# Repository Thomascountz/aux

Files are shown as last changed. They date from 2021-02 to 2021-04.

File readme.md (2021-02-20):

# Aux countz research logo

Aux (short for auxiliary) is an internet-connected consumer electronic device that collects and displays locally captured and internet queried data.

## This Repository
This repository houses [research](research/), firmware, and hardware designs for Aux.

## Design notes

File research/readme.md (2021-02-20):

# Research
Aux requires and immense amount of research and prototyping. Each component/feature is independently documented and later integrated into final designs. Categorizing/archiving this research also allows for the output of documentation and reference material to aid to future designs.

## [Beep](beep/)
Beep contains the research and prototyping for adding audio feedback to Aux.

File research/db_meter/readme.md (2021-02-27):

# Decibel Meter

## References 
- https://blog.yavilevich.com/2016/08/arduino-sound-level-meter-and-spectrum-analyzer/

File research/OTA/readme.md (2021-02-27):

# Over-the-air Updates

## References
- https://tttapa.github.io/ESP8266/Chap13%20-%20OTA.html
- https://github.com/espressif/arduino-esp32/blob/master/libraries/ArduinoOTA/examples/BasicOTA/BasicOTA.ino
- https://docs.platformio.org/en/latest/platforms/espressif32.html#using-built-in-local-solution

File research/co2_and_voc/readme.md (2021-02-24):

# CO2 & VOC
Aux can sense eCO2 (equivalent carbon dioxide) concentrations and TVOC (total volatile organic compound) levels. Together with [temp_and_humidity](research/temp_and_humidity/), this makes up Aux's sense of indoor environment quality.

## [Firmware](/research/co2_and_vcc/firmware/)
This beep prototype is written in Arduino-compatible C++ using the [PlatformIO IDE](https://platformio.org/). Readings are read out through the serial port.

## [Hardware](/research/co2_and_vcc/hardware/)
The circuit is designed with [KiCAD](https://kicad.org/) and consists the ESP32 dev board and a S17021 (a.k.a. SHT71, HTU21, or GY21) sensor module.

## Resources
- https://learn.adafruit.com/adafruit-ccs811-air-quality-sensor/overview

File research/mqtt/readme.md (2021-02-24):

# MQTT
Aux communicates via MQTT (Message Queuing Telemetry Transport) over WIFI. 

## [Firmware](/research/temp_and_humidity/firmware/)
This MQTT prototype is written in Arduino-compatible C++ using the [PlatformIO IDE](https://platformio.org/). The MQTT client is built using the [knolleary/pubsubclient](https://github.com/knolleary/pubsubclient/tree/master/examples) library. The broker is built using the cloud-based managed tool [MyQttHub](https://myqtthub.com/).

## Hardware
This prototype doesn't require a schematic. The onboard `BUILTIN_LED` is toggled via an MQTT topic.

## Resources
- https://support.asplhosting.com/t/connecting-with-pubsubclient-with-myqtthub-arduino-client-for-mqtt/278
- https://learn.sparkfun.com/tutorials/introduction-to-mqtt/all

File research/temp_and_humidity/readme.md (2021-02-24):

# Temp and Humidity
Aux sense local temperature and humidity (via a temperature & humidity sensor) as well as query for outdoor conditions via WIFI.

## [Firmware](/research/temp_and_humidity/firmware/)
This temperature and humidity prototype is written in Arduino-compatible C++ using the [PlatformIO IDE](https://platformio.org/). Readings are read out through the serial port.

## [Hardware](/research/temp_and_humidity/hardware/)
The circuit is designed with [KiCAD](https://kicad.org/) and consists the ESP32 dev board and a S17021 (a.k.a. SHT71, HTU21, or GY21) sensor module.

## Resources
- https://github.com/adafruit/Adafruit_Si7021
- https://learn.adafruit.com/adafruit-si7021-temperature-plus-humidity-sensor
- https://learn.sparkfun.com/tutorials/si7021-humidity-and-temperature-sensor-hookup-guide
- https://revspace.nl/CJMCU-810
- https://learn.sparkfun.com/tutorials/ccs811-air-quality-breakout-hookup-guide

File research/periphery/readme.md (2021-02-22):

# Periphery

Periphery is all of the research that sits adjacent to the project, rather than specifically associated to a single experiment or prototype.

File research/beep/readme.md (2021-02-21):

# Beep
Aux communicates to the user via tone gestures. Think of the sound your phone or laptop makes when you plug in the charger or the sound your computer makes when theres an error. These tones are generated via a piezoelectric buzzer.

## [Firmware](/research/beep/firmware/)
This beep prototype is written in Arduino-compatible C++ using the [PlatformIO IDE](https://platformio.org/). Pressing the button plays the [hello](gestures/hello.mp3) gesture.

## [Gestures](/research/beep/gestures/)
I designed the monophonic gestures using beepbox.co/. It's a simple tool to quickly prototype and export mp3. All gestures have C as the tonal center, this will hopefully allow major and minor notes convey positive and negative feedback. For example, the "alert" tone is a repetition of E♭. Without a C instantly present, it may not feel minor, but as the relationship with the device builds, I hope that the tonal center will be reinforced and allow for the E♭ to be felt as minor on its own.

- [hello.mp3](gestures/hello.mp3)
- [goodbye.mp3](gestures/goodbye.mp3)
- [well_done.mp3](gestures/well_done.mp3)
- [success.mp3](gestures/success.mp3)
- [systems_ok.mp3](gestures/systems_ok.mp3)
- [melancholy.mp3](gestures/melancholy.mp3)
- [shrug.mp3](gestures/shrug.mp3)
- [sorry.mp3](gestures/sorry.mp3)
- [alert.mp3](gestures/alert.mp3)
- [danger.mp3](gestures/danger.mp3)

## [Hardware](/research/beep/hardware/)
The circuit is designed with [KiCAD](https://kicad.org/) and consists the ESP32 dev board, a passive piezoelectric buzzer, and a momentary tactile button switch.

## Resources
- https://www.arduino.cc/reference/en/language/functions/advanced-io/tone/
- https://github.com/r0oland/ESP32_mini_KiCad_Library
- https://github.com/lbernstone/Tone32

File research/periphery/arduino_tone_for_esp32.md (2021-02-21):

# Arduino Tone for ESP32

Arduino has a built-in [`tone()`](https://www.arduino.cc/reference/en/language/functions/advanced-io/tone/) library which allows you to send a PWM `frequency` at 50% duty cycle to a specific `pin` in order to generate a tone on a piezoelectric buzzer with an optional `duration`.

```c
tone(pin, frequency)
tone(pin, frequency, duration)
```

This functionality is [famously](https://github.com/espressif/arduino-esp32/issues/980) [unavailable](https://github.com/espressif/arduino-esp32/issues/1720) in Espressif's [arduino-esp32](https://github.com/espressif/arduino-esp32) library and members of the community have found various [work-arounds](https://github.com/lbernstone/Tone) such as using the native [LED Control](https://docs.espressif.com/projects/esp-idf/en/latest/esp32/api-reference/peripherals/ledc.html) functions to generate PWM signals.

However, looking more closely at [arduino-esp32](https://github.com/espressif/arduino-esp32) library, not only has Espressif provided a clean API for generating tones, they've provided an interface for generating specific PWM frequencies for specific notes on the chromatic scale in different octaves.

```c
double ledcWriteNote(uint8_t chan, note_t note, uint8_t octave){
  const uint16_t noteFrequencyBase[12] = {
  //   C        C#       D        Eb       E        F       F#        G       G#        A       Bb        B
      4186,    4435,    4699,    4978,    5274,    5588,    5920,    6272,    6645,    7040,    7459,    7902
  };

  if(octave > 8 || note >= NOTE_MAX){
      return 0;
  }
  double noteFreq =  (double)noteFrequencyBase[note] / (double)(1 << (8-octave));
  return ledcWriteTone(chan, noteFreq);
}

```

Although not directly compatible with Arduino's `tone()`, the function provides a dedicated interface for producing named frequencies out of the box via the `note_t` type.

```c
typedef enum {
    NOTE_C, NOTE_Cs, NOTE_D, NOTE_Eb, NOTE_E, NOTE_F, NOTE_Fs, NOTE_G, NOTE_Gs, NOTE_A, NOTE_Bb, NOTE_B, NOTE_MAX
} note_t;
```

## Example Usage
I'll take an example from [@lbernstone](https://github.com/lbernstone)'s [Tone32](https://github.com/lbernstone/Tone) library. Their library is a great solution for providing cross-compatibility between code written for an Arduino and code written for an ESP32.

```c
void loop() {
  tone(BUZZER_PIN, NOTE_C4, 500, BUZZER_CHANNEL);
  noTone(BUZZER_PIN, BUZZER_CHANNEL);
  tone(BUZZER_PIN, NOTE_D4, 500, BUZZER_CHANNEL);
  noTone(BUZZER_PIN, BUZZER_CHANNEL);
  tone(BUZZER_PIN, NOTE_E4, 500, BUZZER_CHANNEL);
  noTone(BUZZER_PIN, BUZZER_CHANNEL);
  tone(BUZZER_PIN, NOTE_F4, 500, BUZZER_CHANNEL);
  noTone(BUZZER_PIN, BUZZER_CHANNEL);
  tone(BUZZER_PIN, NOTE_G4, 500, BUZZER_CHANNEL);
  noTone(BUZZER_PIN, BUZZER_CHANNEL);
  tone(BUZZER_PIN, NOTE_A4, 500, BUZZER_CHANNEL);
  noTone(BUZZER_PIN, BUZZER_CHANNEL);
  tone(BUZZER_PIN, NOTE_B4, 500, BUZZER_CHANNEL);
  noTone(BUZZER_PIN, BUZZER_CHANNEL);
}
```

In this example, a major C scale is played while holding each note for 0.5 seconds. The `BUZZER_CHANNEL` argument is optional. In the case of an ESP32, there are 16 PWM channels which can generate independent waveforms which need to explicitly assigned to any PWM-capable pin.

Here is the equivalent scale programmed using `ledcWriteNote()`.

```c
void loop() {
  ledcAttachPin(BUZZER_PIN, BUZZER_CHANNEL);
  ledcWriteNote(BUZZER_CHANNEL, NOTE_C, 4);
  delay(500);
  ledcWriteNote(BUZZER_CHANNEL, NOTE_D, 4);
  delay(500);
  ledcWriteNote(BUZZER_CHANNEL, NOTE_E, 4);
  delay(500);
  ledcWriteNote(BUZZER_CHANNEL, NOTE_F, 4);
  delay(500);
  ledcWriteNote(BUZZER_CHANNEL, NOTE_G, 4);
  delay(500);
  ledcWriteNote(BUZZER_CHANNEL, NOTE_A, 4);
  delay(500);
  ledcWriteNote(BUZZER_CHANNEL, NOTE_B, 4);
  delay(500);
  ledcDetachPin(pin)
}
```

The tradeoff here is that this is not cross-compatible with an Arduino, however, it means not having to import an external library or having to define note frequencies yourself. Similar to Arduino's `tone()`, each signal is produced at 50% duty cycle. Under the hood, both implementations are calling `ledcWriteTone`.

## References
- https://randomnerdtutorials.com/esp32-pwm-arduino-ide/
- https://github.com/espressif/arduino-esp32/issues/1720
- https://community.platformio.org/t/tone-not-working-on-espressif32-platform/7587

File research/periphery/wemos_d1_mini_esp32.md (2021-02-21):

# Wemos D1 Mini ESP32

The [Wemos D1 Mini](https://www.wemos.cc/en/latest/d1/d1_mini.html) is a popular ESP8266 development module in a small form factor. The D1 Mini ESP32 is a generic ESP32 development module that is _not_ created by Wemos, but has a similar footprint to allow interfacing with shields designed for the origin D1 Mini.

In [PlatformIO](https://platformio.org), the board is configured as "[WeMos D1 MINI ESP32](https://docs.platformio.org/en/latest/boards/espressif32/wemos_d1_mini32.html)"

The board features two rows of headers, the inner of the two have a white silkscreen border and indicates the pinout of the original D1 Mini onto which sockets can be soldered to interface with shields. The outer of the two rows has a unique pinout for the ESP32 and its upgraded features.

These can be purchased through several Chinese manufactures and reseller through online marketplaces.

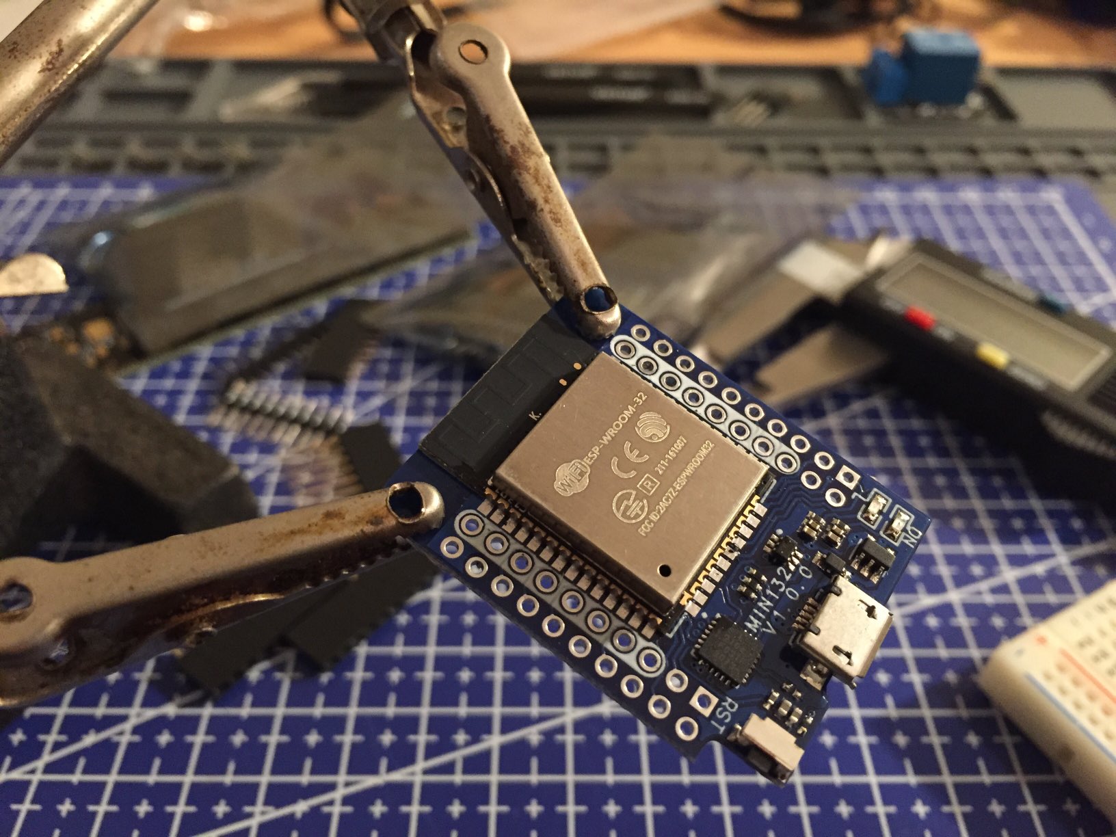
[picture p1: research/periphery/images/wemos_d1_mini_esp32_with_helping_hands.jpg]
wemos d1 mini

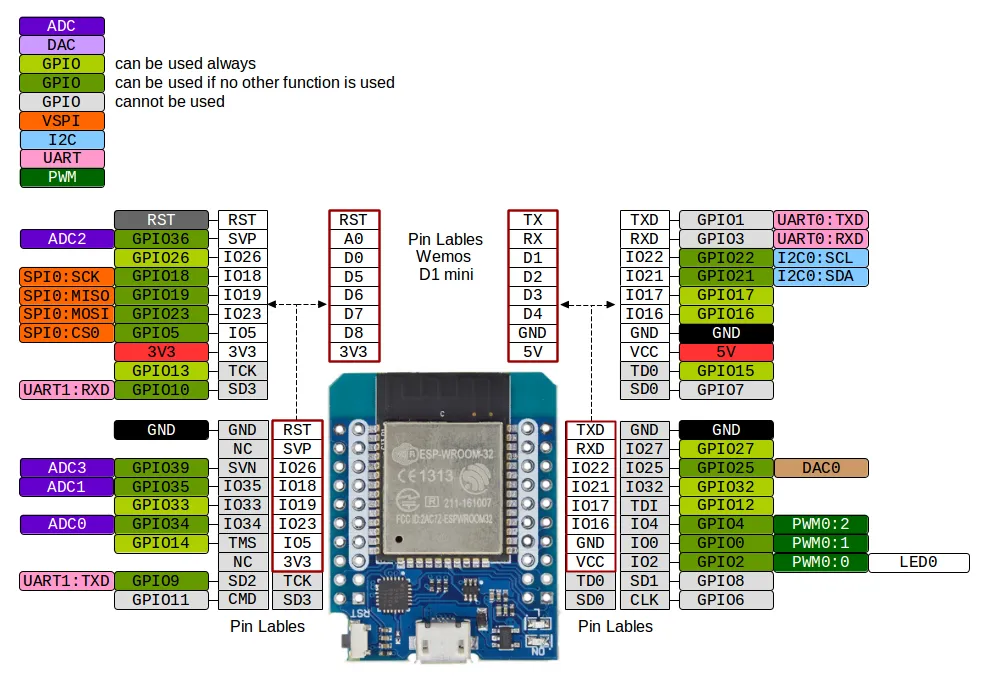
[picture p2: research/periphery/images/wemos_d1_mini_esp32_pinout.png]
wemos d1 mini pinout


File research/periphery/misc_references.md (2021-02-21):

# Misc References

- https://hackaday.com/2016/11/17/creating-a-pcb-in-everything-kicad-part-1/

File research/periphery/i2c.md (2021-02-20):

# Inter-Integrated Circuit Communication Bus

I2C (or I²C) is a communication protocol for integrated circuits, namely microprocessors. It's an alternative to SPI (Serial Peripheral Interface) and UART (Universal Asynchronous Receiver Transmitter) protocols.

The core benefit of I2C is that is allows for many "follower" components to bidirectionally communication to a main "leader" component with only 2 logic wires, VCC, and ground. A leader initiates communication to a specific follower by sending out the follower's address. If the follower hears its address, it acknowledges that it is ready to send or receive data.

## Physical Bus

The two logic wires are SCL, serial clock line used to synchronize the devices communicated with each other, and SDA, serial data line. These two lines are connected to all of the devices on the I2C bus. Both SCL and SDA are open drain drivers, which means that devices communicating on the bus can drive the lines to logic low through a common ground line. Therefore, the two data lines must be pulled to a logic high by using pull-up resistors.

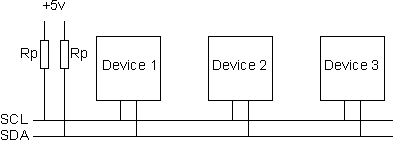
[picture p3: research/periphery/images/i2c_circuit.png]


## Leaders & Followers

Devices on the I2C bus are either **leaders** or **followers**.

The **leader** device drives the SCL (clock line), which initiates the transmission of data across the SDA (data line) bidirectionally: either from the leader to the follower or from the follower to the leader. This means that a **follower** device cannot initiate communication across the bus.

**Old Terminology** — In antiquated texts and diagrams, you may see leader devices referred to as *"masters"* and follower devices referred to as *"slaves."*

There are often many followers connected to an I2C bus, but most often only one leader. It is possible to configure a bus to have multiple leaders. In this scenario, only one leader can control the SCL (clock line) at a time.

**Multi-Leader I2C** — ****At the time of writing, I have not come into a situation that has called for using multiple leaders on an I2C bus, therefore, I have not researched this configuration at length.

## Physical Protocol

Communication across the bus begins when the leader sends out a **start sequence**, which followed by an **address frame**. Once acknowledged, then comes one ore more 8-bit **data frames** (which are each followed by an **acknowledgement bit**). Finally the communication concludes with the leader sending a **stop sequence**.

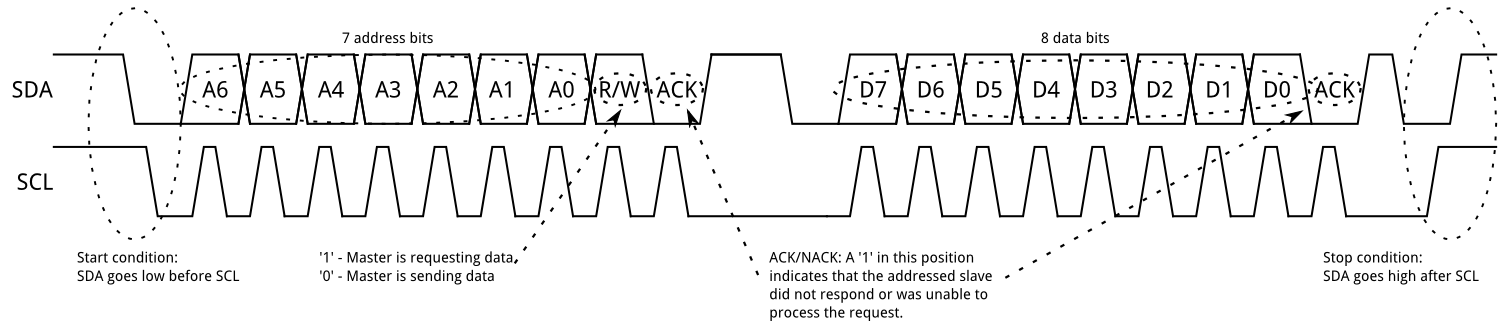
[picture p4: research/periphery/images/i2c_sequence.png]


source: Sparkfun electronics

### Start Sequence

The start sequence happens when the leader is ready to send or request data on the bus. To do this, the master pulls SDA (data line) low while SCL (clock line) remains high. The start and stop sequence are the only times when SDA changes while SCL is high.

### Address Frame

Leaders must know the addresses of followers in order to communicate with them. The address frame follows immediately after the start sequence, and contains 9 bits: the first seven bits are used for the follower's **7-bit address** with the [most significant bit](/research/periphery/most_significant_bit.md) (MSB) first, and the eighth bit is the **read/write bit** and is is used to indicate whether the leader will **read** (`1`) or **write** (`0`). The ninth and final bit of the address frame is the **ACK/NACK bit** (acknowledge/negative acknowledge).

This ACK/NACK happens on the ninth clock pulse when control over SDA (data line) is given to the receiver, in this case, the follower with the address transmitted in the address frame. To acknowledge that the follower is ready, it pulls SDA (data line) low. If on the ninth clock pulse SDA (data line) is still high, it is assumed that the receiving device either did not receive the data or did not know how to parse the message. In this case, it is up to the leader to recover.

### Data Frame

After the start sequence, address frame, and acknowledgement, **data frames** can begin to be transmitted over SDA (data line), again with the [most significant bit](/research/periphery/most_significant_bit.md) first. The leader will continue control over the SCL (clock line), and either the leader or follower will transmit 8 bits of data on SDA depending on the read/write bit in the address frame. The number of frames is dictated by the size of the message being transmitted.

After each 8-bit frame, a ninth bit, again, represents an ACK/NACK. This is controlled by the receiver, which can either be the follower, when in write mode, or the leader, when in read mode.

### Stop Sequence

After all of the data frames are transmitted, the leader will generate a stop sequence by **allowing SDA (data line) to go high *while* SCL (clock line) is high**. During data transmission, SDA (data line) does not change while SCL (clock line) is high.

## Resources

- [https://www.robot-electronics.co.uk/i2c-tutorial](https://www.robot-electronics.co.uk/i2c-tutorial)
- [https://learn.sparkfun.com/tutorials/i2c/all](https://learn.sparkfun.com/tutorials/i2c/all)

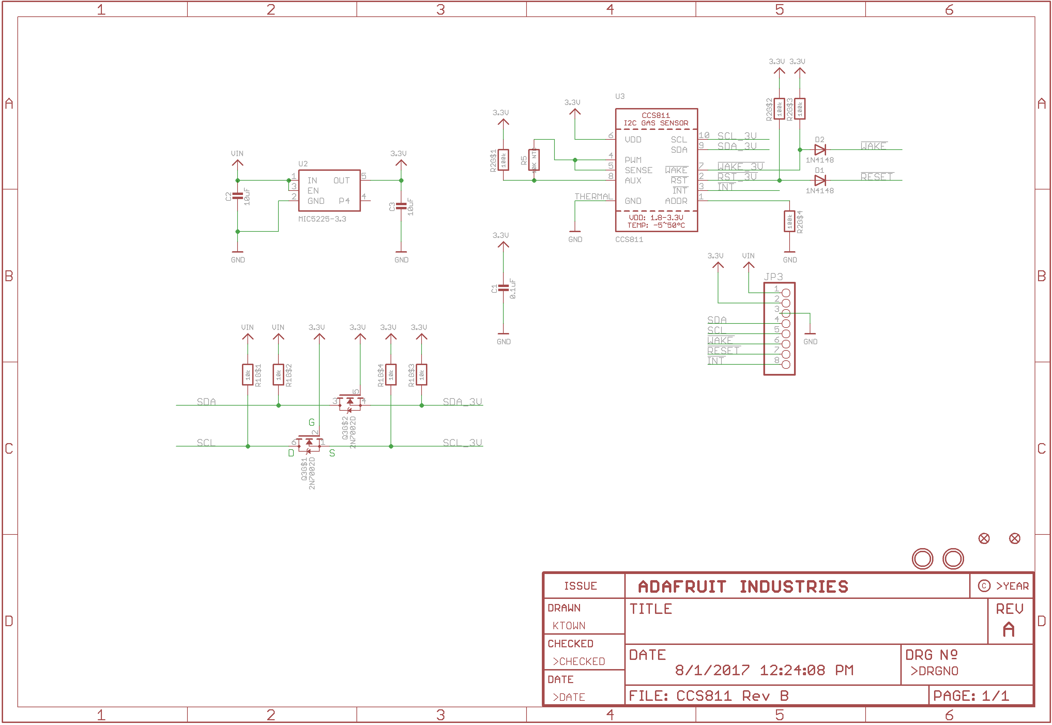
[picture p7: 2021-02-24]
research/co2_and_voc/hardware/CCS811_module_schematic.png

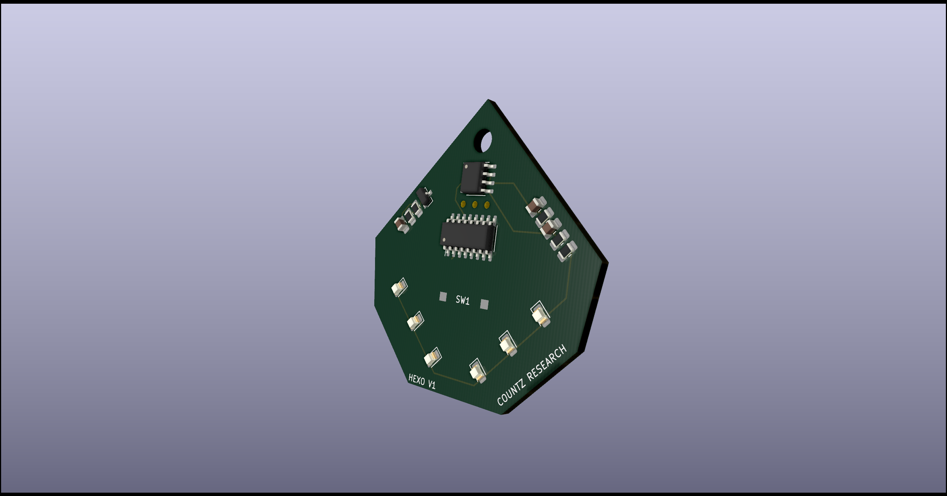
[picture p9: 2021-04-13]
Hexo/init_board_1.png

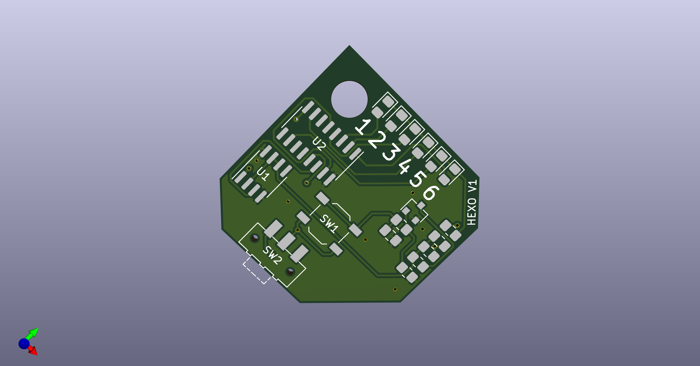
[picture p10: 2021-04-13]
Hexo/hexo_final_front.png

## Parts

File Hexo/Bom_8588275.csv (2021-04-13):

Manufacturer Part Number | Manufacturer | Digi-Key Part Number | Customer Reference | Reference Designator | Packaging | Part Status | Quantity | Unit Price | Extended Price | Quantity Available | Mfg Std Lead Time | Description | RoHS Status | Lead Free Status | REACH Status
ICM7555IBAZ-T | Renesas Electronics America Inc | ICM7555IBAZ-TCT-ND |  | U1 | Cut Tape (CT) | Active | 10 | 0.66500 | $6.65 | 46013 | 14 Weeks | IC OSC SINGLE TIMER 1MHZ 8-SOIC | ROHS3 Compliant | Lead free | REACH Unaffected
BC857BLT3G | ON Semiconductor | BC857BLT3GOSCT-ND |  | Q1 | Cut Tape (CT) | Active | 10 | 0.09300 | $0.93 | 34828 | 44 Weeks | TRANS PNP 45V 100MA SOT23-3 | ROHS3 Compliant | Lead free | REACH Unaffected
S8211-46R | Harwin Inc. | 952-1735-1-ND |  | BAT1 | Cut Tape (CT) | Active | 5 | 0.87000 | $4.35 | 3158 | 28 Weeks | BATTERY RETAINER COIN 20MM SMD | ROHS3 Compliant | Lead free | REACH Unaffected
CR2032VP | Energizer Battery Company | N189-ND | CR2032 |  | Bulk | Active | 5 | 0.50000 | $2.50 | 440700 | 18 Weeks | BATTERY LITHIUM 3V COIN 20MM | Not applicable | Lead free | Not Available
TL3342F160QG/TR | E-Switch | EG2531CT-ND |  | SW1 | Cut Tape (CT) | Active | 5 | 0.59000 | $2.95 | 27562 | 12 Weeks | SWITCH TACTILE SPST-NO 0.05A 12V | ROHS3 Compliant | Lead free | REACH Unaffected
JS102011SAQN | C&K | 401-1999-1-ND |  | SW2 | Cut Tape (CT) | Active | 5 | 0.63000 | $3.15 | 8178 | 11 Weeks | SWITCH SLIDE SPDT 300MA 6V | ROHS3 Compliant | Lead free | REACH Unaffected
CD74HC4017M96 | Texas Instruments | 296-12808-1-ND |  | U2 | Cut Tape (CT) | Active | 5 | 0.56000 | $2.80 | 3210 | 6 Weeks | IC DECADE COUNTER/DIVIDER 16SOIC | ROHS3 Compliant | Lead free | REACH Unaffected
RC0805FR-0710ML | Yageo | 311-10.0MCRCT-ND |  | R1 | Cut Tape (CT) | Active | 10 | 0.04200 | $0.42 | 358114 | 20 Weeks | RES SMD 10M OHM 1% 1/8W 0805 | ROHS3 Compliant | Lead free | REACH Unaffected
RC0805FR-074M7L | Yageo | 311-4.70MCRCT-ND |  | R2 | Cut Tape (CT) | Active | 10 | 0.04200 | $0.42 | 37 | 20 Weeks | RES SMD 4.7M OHM 1% 1/8W 0805 | ROHS3 Compliant | Lead free | REACH Unaffected
RC0805FR-073M3L | Yageo | 311-3.30MCRCT-ND |  | R3 | Cut Tape (CT) | Active | 10 | 0.04200 | $0.42 | 32416 | 20 Weeks | RES SMD 3.3M OHM 1% 1/8W 0805 | ROHS3 Compliant | Lead free | REACH Unaffected
RC0805FR-07470RL | Yageo | 311-470CRCT-ND |  | R5 | Cut Tape (CT) | Active | 10 | 0.04200 | $0.42 | 140893 | 20 Weeks | RES SMD 470 OHM 1% 1/8W 0805 | ROHS3 Compliant | Lead free | REACH Unaffected
RC0805FR-0710KL | Yageo | 311-10.0KCRCT-ND |  | R4 | Cut Tape (CT) | Active | 10 | 0.04200 | $0.42 | 10496303 | 20 Weeks | RES SMD 10K OHM 1% 1/8W 0805 | ROHS3 Compliant | Lead free | REACH Unaffected
CC0805ZRY5V7BB104 | Yageo | 311-4354-1-ND | C2 |  | Cut Tape (CT) | Active | 10 | 0.08900 | $0.89 | 10125 | 20 Weeks | CAP CER 0.1UF 16V Y5V 0805 | ROHS3 Compliant | Lead free | REACH Unaffected
CC0805ZRY5V7BB105 | Yageo | 311-1457-1-ND | C1 |  | Cut Tape (CT) | Active | 10 | 0.10200 | $1.02 | 80773 | 24 Weeks | CAP CER 1UF 16V Y5V 0805 | ROHS3 Compliant | Lead free | REACH Unaffected
EAST2012AA1 | Everlight Electronics Co Ltd | 1080-EAST2012AA1CT-ND | D1-D6 |  | Cut Tape (CT) | Active | 45 | 0.14000 | $6.30 | 747 | 12 Weeks | PCB TOP VIEW SMD LED ORANGE | ROHS3 Compliant | Not Available | Not Available

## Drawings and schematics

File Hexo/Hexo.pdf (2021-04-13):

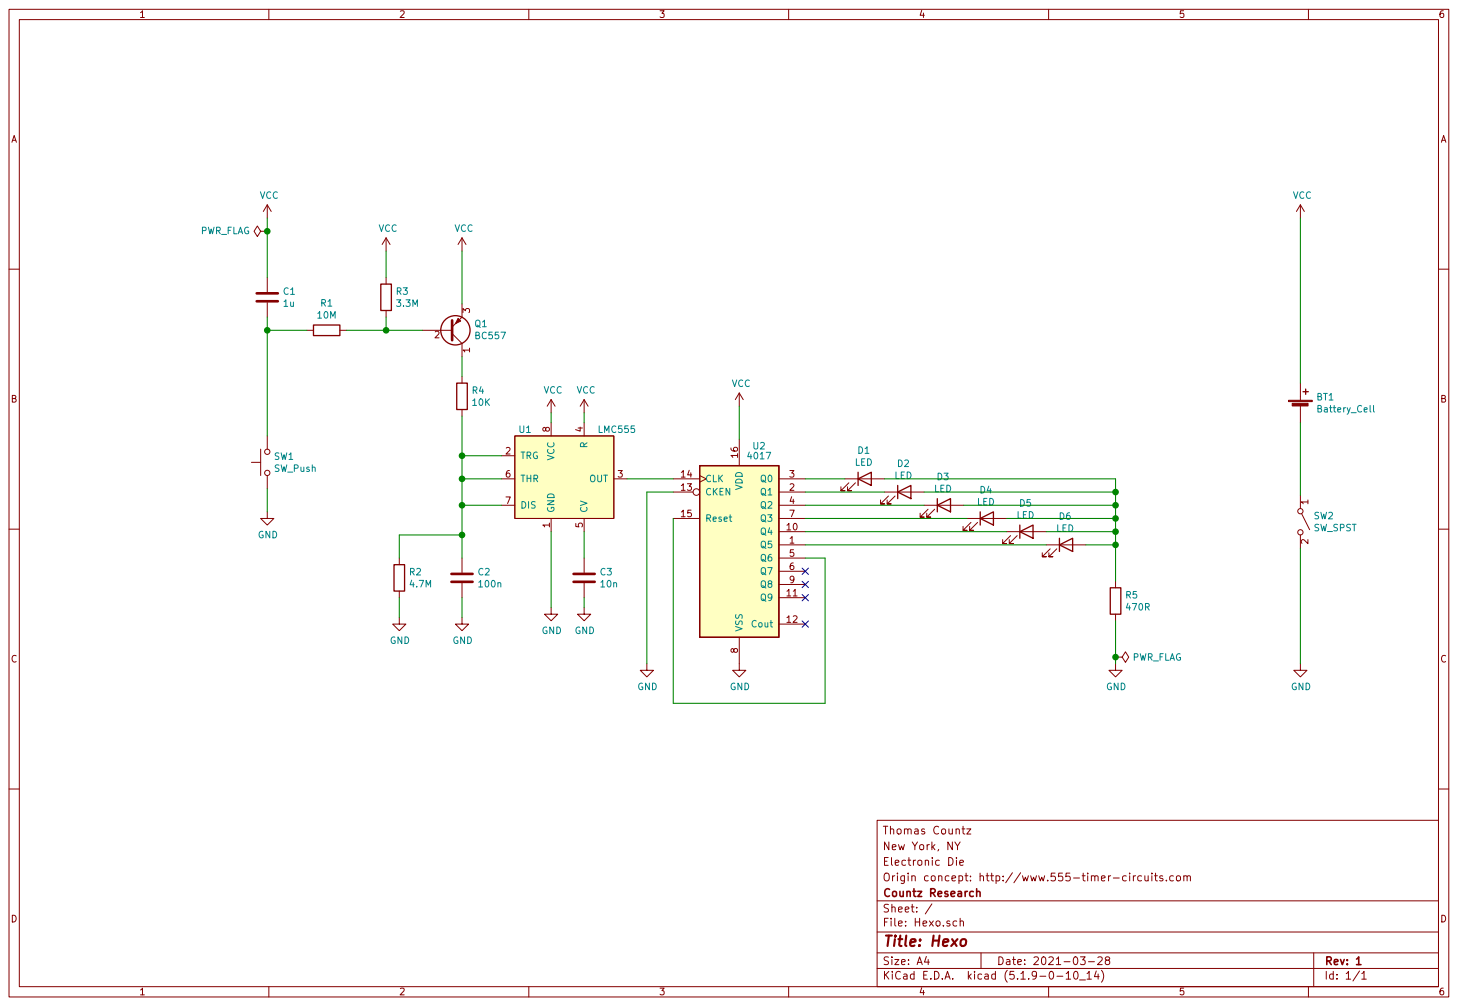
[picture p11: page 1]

Electronic Die New York, NY

File: Hexo.sch Sheet: / Countz Research Origin concept: http://www.555-timer-circuits.com

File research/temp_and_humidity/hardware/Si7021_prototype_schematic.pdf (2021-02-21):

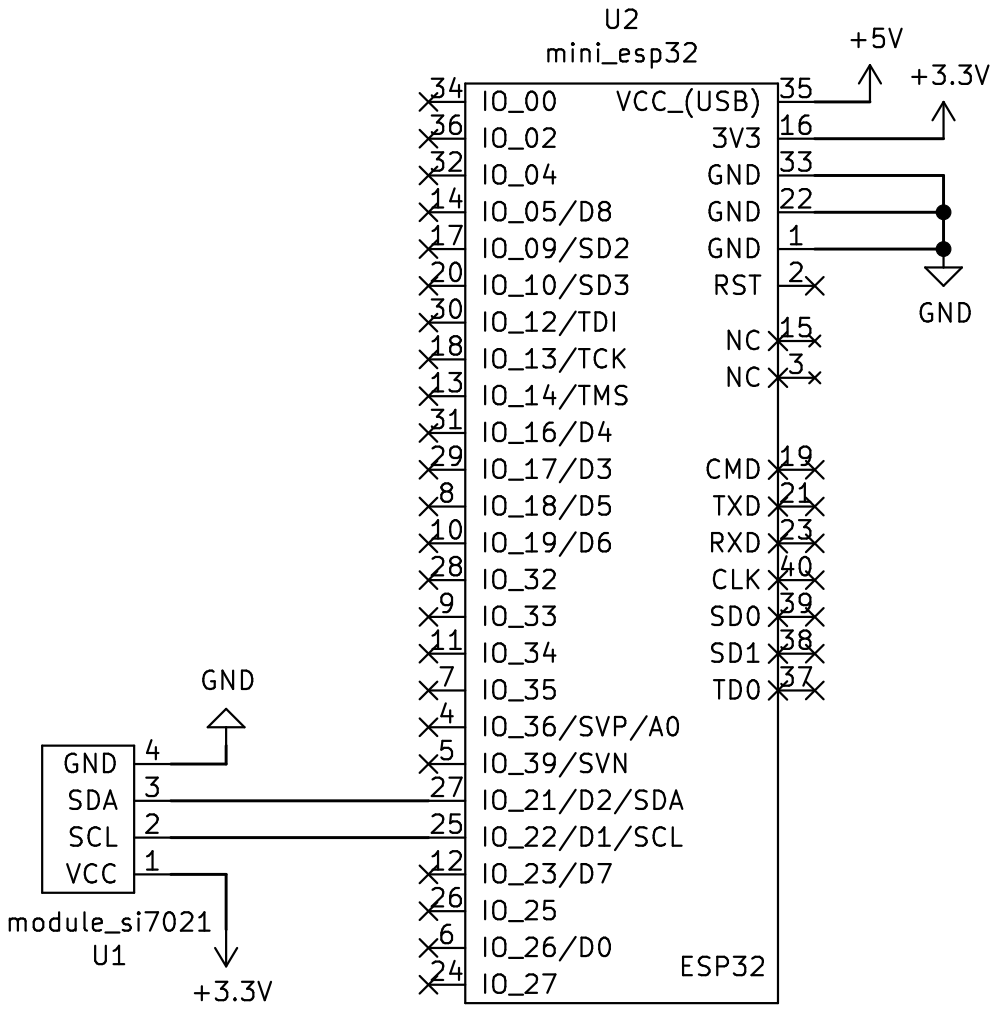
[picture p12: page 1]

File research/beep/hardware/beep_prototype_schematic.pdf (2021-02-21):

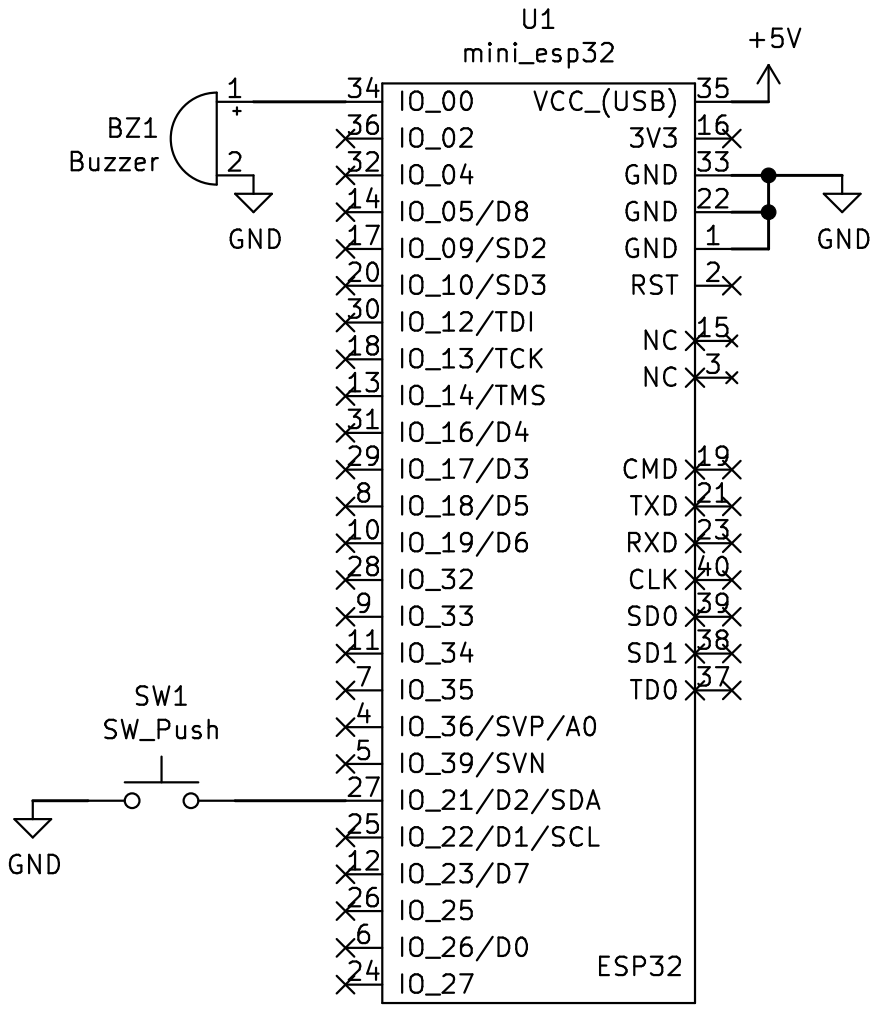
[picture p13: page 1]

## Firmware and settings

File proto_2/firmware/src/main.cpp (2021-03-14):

// I2C device class (I2Cdev) demonstration Arduino sketch for MPU6050 class
// 10/7/2011 by Jeff Rowberg <jeff@rowberg.net>
// Updates should (hopefully) always be available at https://github.com/jrowberg/i2cdevlib
//
// Changelog:
//      2013-05-08 - added multiple output formats
//                 - added seamless Fastwire support
//      2011-10-07 - initial release

/* ============================================
I2Cdev device library code is placed under the MIT license
Copyright (c) 2011 Jeff Rowberg

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
THE SOFTWARE IS PROVIDED "AS IS", WITHOUT WARRANTY OF ANY KIND, EXPRESS OR
IMPLIED, INCLUDING BUT NOT LIMITED TO THE WARRANTIES OF MERCHANTABILITY,
FITNESS FOR A PARTICULAR PURPOSE AND NONINFRINGEMENT. IN NO EVENT SHALL THE
AUTHORS OR COPYRIGHT HOLDERS BE LIABLE FOR ANY CLAIM, DAMAGES OR OTHER
LIABILITY, WHETHER IN AN ACTION OF CONTRACT, TORT OR OTHERWISE, ARISING FROM,
OUT OF OR IN CONNECTION WITH THE SOFTWARE OR THE USE OR OTHER DEALINGS IN
THE SOFTWARE.
===============================================
*/

#include <Arduino.h>
#include <Adafruit_SSD1306.h>
// I2Cdev and MPU6050 must be installed as libraries, or else the .cpp/.h files
// for both classes must be in the include path of your project
#include "I2Cdev.h"
#include "MPU6050.h"

// Arduino Wire library is required if I2Cdev I2CDEV_ARDUINO_WIRE implementation
// is used in I2Cdev.h
#if I2CDEV_IMPLEMENTATION == I2CDEV_ARDUINO_WIRE
    #include "Wire.h"
#endif

// class default I2C address is 0x68
// specific I2C addresses may be passed as a parameter here
// AD0 low = 0x68 (default for InvenSense evaluation board)
// AD0 high = 0x69
MPU6050 accelgyro;
//MPU6050 accelgyro(0x69); // <-- use for AD0 high

int16_t ax, ay, az;
int16_t gx, gy, gz;



// uncomment "OUTPUT_READABLE_ACCELGYRO" if you want to see a tab-separated
// list of the accel X/Y/Z and then gyro X/Y/Z values in decimal. Easy to read,
// not so easy to parse, and slow(er) over UART.
#define OUTPUT_READABLE_ACCELGYRO

// uncomment "OUTPUT_BINARY_ACCELGYRO" to send all 6 axes of data as 16-bit
// binary, one right after the other. This is very fast (as fast as possible
// without compression or data loss), and easy to parse, but impossible to read
// for a human.
//#define OUTPUT_BINARY_ACCELGYRO


bool blinkState = false;

Adafruit_SSD1306 display = Adafruit_SSD1306(128, 64, &Wire);

void setup() {
    // join I2C bus (I2Cdev library doesn't do this automatically)
    #if I2CDEV_IMPLEMENTATION == I2CDEV_ARDUINO_WIRE
        Wire.begin();
    #elif I2CDEV_IMPLEMENTATION == I2CDEV_BUILTIN_FASTWIRE
        Fastwire::setup(400, true);
    #endif

    // initialize serial communication
    // (38400 chosen because it works as well at 8MHz as it does at 16MHz, but
    // it's really up to you depending on your project)
    Serial.begin(115200);

    // initialize device
    Serial.println("Initializing I2C devices...");
    accelgyro.initialize();

    // verify connection
    Serial.println("Testing device connections...");
    Serial.println(accelgyro.testConnection() ? "MPU6050 connection successful" : "MPU6050 connection failed");

    // use the code below to change accel/gyro offset values
    /*
    Serial.println("Updating internal sensor offsets...");
    // -76	-2359	1688	0	0	0
    Serial.print(accelgyro.getXAccelOffset()); Serial.print("\t"); // -76
    Serial.print(accelgyro.getYAccelOffset()); Serial.print("\t"); // -2359
    Serial.print(accelgyro.getZAccelOffset()); Serial.print("\t"); // 1688
    Serial.print(accelgyro.getXGyroOffset()); Serial.print("\t"); // 0
    Serial.print(accelgyro.getYGyroOffset()); Serial.print("\t"); // 0
    Serial.print(accelgyro.getZGyroOffset()); Serial.print("\t"); // 0
    Serial.print("\n");
    accelgyro.setXGyroOffset(220);
    accelgyro.setYGyroOffset(76);
    accelgyro.setZGyroOffset(-85);
    Serial.print(accelgyro.getXAccelOffset()); Serial.print("\t"); // -76
    Serial.print(accelgyro.getYAccelOffset()); Serial.print("\t"); // -2359
    Serial.print(accelgyro.getZAccelOffset()); Serial.print("\t"); // 1688
    Serial.print(accelgyro.getXGyroOffset()); Serial.print("\t"); // 0
    Serial.print(accelgyro.getYGyroOffset()); Serial.print("\t"); // 0
    Serial.print(accelgyro.getZGyroOffset()); Serial.print("\t"); // 0
    Serial.print("\n");
    */

   accelgyro.setXAccelOffset(-1343);
   accelgyro.setYAccelOffset(575);
   accelgyro.setZAccelOffset(1257);
   accelgyro.setXGyroOffset(57);
   accelgyro.setYGyroOffset(103);
   accelgyro.setZGyroOffset(-66);

    // configure Arduino LED pin for output
    pinMode(BUILTIN_LED, OUTPUT);

    if (!display.begin(SSD1306_SWITCHCAPVCC, 0x3C))
    { // Address 0x3C for 128x32
      Serial.println(F("SSD1306 allocation failed"));
      for (;;)
        ; // Don't proceed, loop forever
    }
    display.clearDisplay();
    display.setTextSize(1);
    display.setTextColor(WHITE);
    display.setRotation(0);
}

void loop() {
  // read raw accel/gyro measurements from device
  accelgyro.getMotion6(&ax, &ay, &az, &gx, &gy, &gz);

  // these methods (and a few others) are also available
  //accelgyro.getAcceleration(&ax, &ay, &az);
  //accelgyro.getRotation(&gx, &gy, &gz);

#ifdef OUTPUT_READABLE_ACCELGYRO
  display.clearDisplay();
  display.setCursor(0, 0);
  // display tab-separated accel/gyro x/y/z values
  Serial.print(ax);
  Serial.print(",");
  Serial.print(ay);
  Serial.print(",");
  Serial.print(az);
  Serial.print(",");
  Serial.print(gx);
  Serial.print(",");
  Serial.print(gy);
  Serial.print(",");
  Serial.println(gz;

  display.println("Accelerometer - m/s^2");
  display.print(ax);
  display.print(", ");
  display.print(ay);
  display.print(", ");
  display.print(az);
  display.println("");

  display.println("Gyroscope - rps");
  display.print(gx);
  display.print(", ");
  display.print(gy);
  display.print(", ");
  display.print(gz);
  display.println("");

  display.display();

  delay(100);
#endif

#ifdef OUTPUT_BINARY_ACCELGYRO
  Serial.write((uint8_t)(ax >> 8));
  Serial.write((uint8_t)(ax & 0xFF));
  Serial.write((uint8_t)(ay >> 8));
  Serial.write((uint8_t)(ay & 0xFF));
  Serial.write((uint8_t)(az >> 8));
  Serial.write((uint8_t)(az & 0xFF));
  Serial.write((uint8_t)(gx >> 8));
  Serial.write((uint8_t)(gx & 0xFF));
  Serial.write((uint8_t)(gy >> 8));
  Serial.write((uint8_t)(gy & 0xFF));
  Serial.write((uint8_t)(gz >> 8));
  Serial.write((uint8_t)(gz & 0xFF));
#endif

  // blink LED to indicate activity
  blinkState = !blinkState;
  digitalWrite(BUILTIN_LED, blinkState);
}

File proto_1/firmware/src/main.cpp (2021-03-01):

#include <Arduino.h>
#include <WiFi.h>
#include <PubSubClient.h>
#include <Adafruit_Si7021.h>
#include <secrets.h>
#include <OTA.h>

// consts
const long thirty_seconds = 30000;
unsigned long last_message_at = 0;

// Beep
const int pwmChannel = 0;
const int buzzerPin = 26;

// WIFI
const char *ssid = SECRET_SSID;
const char *password = SECRET_PASS;

// MQTT Settings
void mqttHandler(char *topic, byte *payload, unsigned int length);
void gestureHello();
const char *mqtt_broker_address = SECRET_MQTT_BROKER_ADDRESS;
const char *client_id = SECRET_MQTT_CLIENT_ID;
const char *client_user = SECRET_MQTT_CLIENT_USER;
const char *client_password = SECRET_MQTT_CLIENT_PASSWORD;
const int port = 1883;
WiFiClient wifi_client = WiFiClient();
PubSubClient client(mqtt_broker_address, port, mqttHandler, wifi_client);

const char *temperature_topic = "thomascountz/feeds/proto-1.temperature";
const char *humidity_topic = "thomascountz/feeds/proto-1.humidity";
const char *beep_topic = "thomascountz/feeds/proto-1.beep";
const char *did_beep_topic = "thomascountz/feeds/proto-1.did-beep";
const char *heartbeat_topic = "thomascountz/feeds/proto-1.heartbeat";
const char *diagnostics_topic = "thomascountz/feeds/proto-1.diagnostics";

char temperature_buffer[8];
char humidity_buffer[8];

// Temp & Humidity
Adafruit_Si7021 temp_sensor = Adafruit_Si7021();
float temperature;
float humidity;

void mqttHandler(char *topic, byte *payload, unsigned int length) {
#ifdef DEBUG
  Serial.print("Message arrived: ");
  Serial.println(topic);
#endif
  if (strcmp(topic, beep_topic) == 0) {
    if ((char)payload[0] == '1') {
      gestureHello();
    }
  }
}

void gestureHello() {
  ledcAttachPin(buzzerPin, pwmChannel);
  ledcWriteNote(pwmChannel, NOTE_C, 6);
  delay(100);
  ledcWriteNote(pwmChannel, NOTE_D, 6);
  delay(100);
  ledcWriteNote(pwmChannel, NOTE_G, 6);
  delay(100);
  ledcWriteNote(pwmChannel, NOTE_E, 6);
  delay(100);
  ledcDetachPin(buzzerPin);
  client.publish(did_beep_topic, "1");
#ifdef DEBUG
  Serial.println("Did beep.");
#endif
}

void setup() {
#ifdef DEBUG
  Serial.begin(115200);
#endif

  // Delay on startup
  delay(2000);

// Initiate temperature/humidity sensor
#ifdef DEBUG
  Serial.println("Initiating temperature & humidity sensor");
#endif
  if (!temp_sensor.begin()) {
    while (true)
      ;
  }

// Connect to WiFi
#ifdef DEBUG
  Serial.println("Connecting to WiFi.");
#endif
  WiFi.begin(ssid, password);
  while (WiFi.status() != WL_CONNECTED) {
    delay(500);
#ifdef DEBUG
    Serial.print(".");
#endif
  }
#ifdef DEBUG
  Serial.println();
  Serial.println("Connected: ");
  Serial.println(WiFi.localIP());
#endif

// Connect to MQTT broker
#ifdef DEBUG
  Serial.println("Connecting to MQTT broker.");
#endif
  if (client.connect(client_id, client_user, client_password)) {
#ifdef DEBUG
    Serial.println("Connected to MQTT broker.");
#endif
    client.publish(heartbeat_topic, "1");
    client.subscribe(beep_topic);
    gestureHello();
  }
  
  // OTA
  OTABegin();
}

void loop() {
  //OTA
  OTAHandle();

  // Are we still connected to the MQTT broker?
  if (!client.connected()) {
    while (!client.connected()) {
#ifdef DEBUG
      Serial.println("Reconnecting to MQTT broker.");
#endif
      if (client.connect(client_id, client_user, client_password)) {
#ifdef DEBUG
        Serial.println("Connected to MQTT broker.");
#endif
        client.publish(heartbeat_topic, "1");
        client.subscribe(beep_topic);
      } else {
#ifdef DEBUG
        Serial.println("Failed to reconnect to MQTT broker.");
        Serial.println("Trying again in 5 seconds");
#endif
        delay(5000);
      }
    }
  }

  client.loop();

  unsigned long now = millis();
  if (now - last_message_at > thirty_seconds) {
    last_message_at = now;
    temperature = temp_sensor.readTemperature();
    humidity = temp_sensor.readHumidity();

#ifdef DEBUG
    Serial.println();
#endif

    dtostrf(temperature, 6, 2, temperature_buffer);
    client.publish(temperature_topic, temperature_buffer);
#ifdef DEBUG
    Serial.print("temperature: ");
    Serial.print(temperature_buffer);
#endif

    dtostrf(humidity, 6, 2, humidity_buffer);
    client.publish(humidity_topic, humidity_buffer);
#ifdef DEBUG
    Serial.print(" humidity: ");
    Serial.print(humidity_buffer);
#endif
  }
}

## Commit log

2021-02-20 begin prototyping firmware for ESP32
2021-02-21 add hardware and update serial out
    [beep_prototype-B_Cu.gbl, beep_prototype-B_Mask.gbs, beep_prototype-B_SilkS.gbo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]
2021-02-21 add document about wemos d1 mini esp32
2021-02-21 use interrupts for beep
2021-02-21 discover ledcWriteNote
2021-02-21 add document about ledcWriteNote
2021-02-21 add Si7021 research
    [si7021_prototype.kicad_pcb, si7021_prototype.sch]
2021-03-14 add g2b work
    [getting_to_blinky-B_Cu.gbr, getting_to_blinky-B_Mask.gbr, getting_to_blinky-B_Paste.gbr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]
2021-04-13 add hexo files
    [Bom_8588275.csv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]
